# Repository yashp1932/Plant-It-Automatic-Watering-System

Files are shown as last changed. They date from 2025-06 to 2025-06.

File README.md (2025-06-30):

# Plant-It — Smart Watering System 🌿

## ⚙️ Summary 

Plant-It is an **embedded IoT project** built around the ESP8266 microcontroller that **automates indoor plant watering**. It combines AI-powered plant species identification (using Pl@ntNet and OpenAI APIs) with real-time soil moisture sensing to deliver precise watering control. The system integrates with a React-based web dashboard for live monitoring, device management, and personalized care instructions.

**Tech Stack:** ESP8266 · Arduino IDE · Capacitive Soil Moisture Sensor · Relay Module · React.js · Google OAuth · Pl@ntNet API · OpenAI API · REST API  

**Key Features:** Automated AI-driven watering · real-time soil monitoring · image-based plant identification · multi-plant dashboard with user authentication.

---
## 🔍 Explore

🌐 https://plantit.site/login      
📄 [Project Overview (PDF)](project_overview.pdf)      
🎥 [Demo Video](https://www.youtube.com/watch?v=a0oCiGJgBCo)

---

## 🌱 Background

My house is filled with plants thanks to my dad, an avid gardener. With so many plants, it was easy to forget which ones needed watering. Plant-It was created to automate watering, delivering the right amount to each plant precisely when needed.

---

## 🧠 How It Works

Plant-It automatically identifies your plant, retrieves watering needs, and waters based on live soil readings:

1. **Plant Identification**  
   - Snap a photo of the plant and upload to the web app
   - Use **Pl@ntNet API** to detect species  

2. **Optimal Moisture Retrieval**  
   - Feed species data to **OpenAI API**  
   - Retrieve ideal min/max/optimal soil moisture %  

3. **Microcontroller Logic**  
   - ESP8266 connects via **WiFi** to a web app  
   - Receives min/max/optimal VWC thresholds (once per session)  
   - Reads soil moisture from sensor  
   - Controls water pump via relay, watering only as needed  
   - Displays live status on **I2C LCD**
   - Potentiometer enables control over how much water flows out the pipe at a given time

4. **Web Dashboard**  
   - Built with **React**  
   - Uses **Google Accounts** for individual sign-in  
   - Per-user dashboard to view all plants  
   - See each plant’s watering status, species, family, and care tips  
   - ESP8266 can be paired to any plant at any time, allowing easy swap devices between plants

---

## 🔧 Tech Stack

- **ESP8266 (NodeMCU)** microcontroller  
- **Arduino IDE** (firmware development)  
- **React.js** (web app for plant dashboard)  
- **Google OAuth** (user authentication)  
- **Pl@ntNet API** (plant species identification)  
- **OpenAI API** (optimal moisture range generation)  
- **HTTP / REST** (device ↔ web app communication)  
- **Wi-Fi networking** (ESP8266 local server)  

---

## ⚡️ Electronics Used

1. **8-channel relay module**  
2. **5V / 3.3V breadboard power supply**  
3. **Potentiometer** (to tune pump flow rate)  
4. **LCM1602 I2C LCD display**  
5. **Capacitive soil moisture sensor v1.2**  
6. **3–6V submersible water pump**  
7. **ESP8266 (NodeMCU)** microcontroller

---

## 📐 Wiring Diagram

Here’s the full wiring for Plant-It (ESP8266, relay, moisture sensor, LCD, pump):

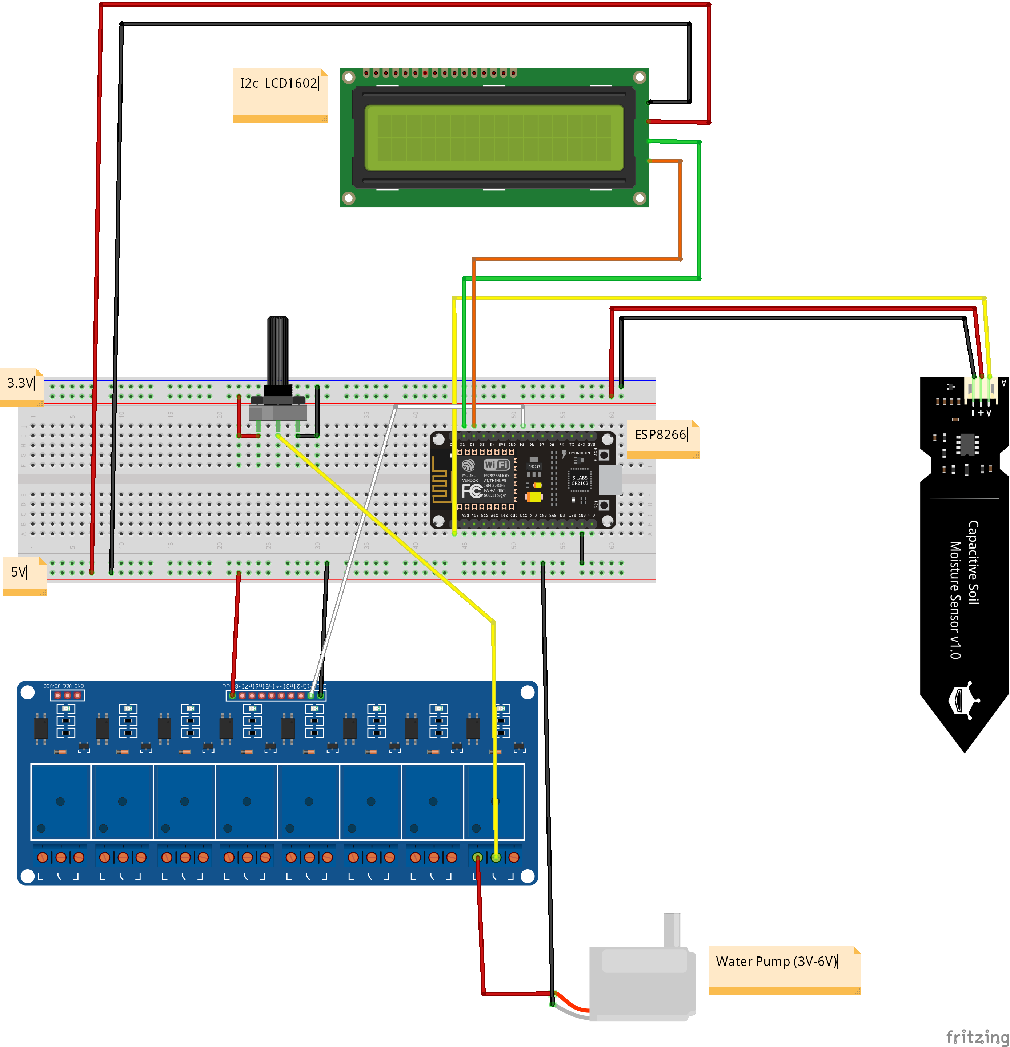
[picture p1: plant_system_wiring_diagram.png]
Plant-It Wiring Diagram


---
## 🚀 Quickstart

```bash
git clone https://github.com/yashp1932/Plant-It-Smart-Watering-System.git
cd Plant-It-Smart-Watering-System
```

**1. In Arduino IDE:**
   - Go to Tools → Board → Boards Manager
   - Install: ESP8266 Boards (by ESP8266 Community)
     
**2. Install required libraries (via Arduino Library Manager):**
   - ESP8266WebServer
   - ArduinoJson
   - LiquidCrystal I2C

**3. Select your board:**
   - Tools → Board → NodeMCU 1.0 (ESP-12E Module)
     
**4. Upload code to ESP8266 (NodeMCU)**      

**5. Power the board — and watch it water!** 🌱

 ---
 
## 🤝 Connect

Have ideas to improve Plant-It? I’d love to hear your feedback, questions, or collaboration ideas!

📧 yash.panchal1932@gmail.com  
🌐 [GitHub](https://github.com/yashp1932)  
💼 [LinkedIn](https://www.linkedin.com/in/yash-panchal-9185aa291/)

📧 Kalpkansara123@gmail.com (project partner)      
🌐 [GitHub](https://github.com/KalpKan/PlantWater)        
💼 [LinkedIn](https://www.linkedin.com/in/kalp-kansara123/)

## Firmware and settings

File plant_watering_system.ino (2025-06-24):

//importing libraries
#include <Wire.h>
#include <LiquidCrystal_I2C.h>
#include <ESP8266WiFi.h>
#include <ESP8266WebServer.h>
#include <ArduinoJson.h>

//storing used pins in variable
#define relayPin    D5    // GPIO14
#define moisturePin A0    // analog input

const int dry         = 452;  // dry calibration
const int wet         = 234;  // wet calibration
const int errorMargin = 3;    // accomodate for sensor errors

// —————— LCD Setup ——————
LiquidCrystal_I2C lcd(0x27, 16, 2);

// —————— Wi-Fi credentials ——————
const char* ssid     = "";
const char* password = "";

// —————— HTTP Server ——————
ESP8266WebServer server(8080); //node on the network it is running on
const char* deviceName = "Plant Watering Device"; //device name to identify on web application

// —————— Plant thresholds ——————
//plant object to hold the properties
struct PlantConfig {
  int minVWC;
  int maxVWC;
  int optimalVWC;
  bool configured;
} plantConfig = {0, 0, 0, false}; //default state

// —————— State ——————
//state variables for watering conditions
bool   isWatering     = false;
bool   thresholdFlag  = false;
String statusMessage  = "";
bool   printedConfig  = false;  // print thresholds once

// — forward declarations —
void connectToWiFi();
void setupWebServer();
int  moisturePercentage(int raw);
void printMoistureAndStatus(int pct, const String &msg);

void setup() {
  Serial.begin(115200); //buad rate for serial communication

  // Relay off initally
  pinMode(relayPin, OUTPUT);
  digitalWrite(relayPin, LOW);

  //Configuring LCD
  lcd.init();
  lcd.backlight();
  lcd.setCursor(0,0); lcd.print("Plant Watering");
  lcd.setCursor(0,1); lcd.print("System Ready!");
  delay(1500);
  lcd.clear();

  connectToWiFi();
  setupWebServer();
  server.begin();

  //Print statements for debugging
  Serial.println("Server listening on port 8080");
  lcd.setCursor(0,0); lcd.print("Waiting for");
  lcd.setCursor(0,1); lcd.print("configuration");
}

void loop() {
  // Always listen for status/configure
  server.handleClient();

  if (!plantConfig.configured) return;

  // Print the thresholds once after config
  if (!printedConfig) {
    Serial.println(">>> Received plant config:");
    Serial.printf("minVWC=%d%%  maxVWC=%d%%  optimalVWC=%d%%\n\n",
                  plantConfig.minVWC,
                  plantConfig.maxVWC,
                  plantConfig.optimalVWC);
    printedConfig = true;
  }

  int raw = analogRead(moisturePin); //read value from sensor
  int pct = moisturePercentage(raw); //convert it to percentage
  Serial.printf("Moisture: %d%%\n", pct); 

  //---------Instructions for when to Water------------
  // Start watering
  if (pct < (plantConfig.minVWC + errorMargin)
      && !isWatering && !thresholdFlag) {
    digitalWrite(relayPin, HIGH);
    isWatering    = true;
    thresholdFlag = false;
    statusMessage = "Watering...     ";
  }
  // Stop watering
  if (isWatering && pct > (plantConfig.optimalVWC + errorMargin)) {
    digitalWrite(relayPin, LOW);
    isWatering    = false;
    thresholdFlag = true;
    statusMessage = "Moisture OK     ";
  }
  // Reset flag
  if (pct > (plantConfig.optimalVWC + 10)) thresholdFlag = false;

  printMoistureAndStatus(pct, statusMessage); //print message on LCD
  delay(2000);
}

void connectToWiFi() {
  //printing on the LCD
  lcd.clear();
  lcd.setCursor(0,0); lcd.print("Connecting WiFi");
  lcd.setCursor(0,1); lcd.print(ssid);

  WiFi.begin(ssid, password); //beginning a connection on the network
  while (WiFi.status() != WL_CONNECTED) { //checking if it is connected
    delay(500);
    Serial.print(".");
  }
  Serial.println("\nWiFi connected");
  //Serial.print("IP = "); Serial.println(WiFi.localIP()); //retrieve the IP address for debugging purposes 

  lcd.clear();
  lcd.setCursor(0,0); lcd.print("WiFi Connected");
  //lcd.setCursor(0,1); lcd.print(WiFi.localIP().toString()); //LCD only accepts string so we have to convert
  delay(2000);
  lcd.clear();
}

void setupWebServer() {
  // Device discovery endpoint
  //checking if plant is configured and has the configured values
  server.on("/status", HTTP_GET, []() {
    server.sendHeader("Access-Control-Allow-Origin", "*");
    server.send(200, "application/json",
                String("{\"device\":\"") + deviceName +
                "\",\"configured\":" + (plantConfig.configured ? "true" : "false") +
                "}");
  });

  // Configure endpoint
  //checking if it recieved the data in JSON format
  server.on("/configure", HTTP_POST, []() {
    if (!server.hasArg("plain")) {
      Serial.println("ERROR: No JSON data received");
      server.send(400, "application/json", "{\"error\":\"No JSON\"}");
      return;
    }
    
    String jsonData = server.arg("plain");
    //debugging purposes to check length of data recieved and what the values are
    Serial.println("=== RECEIVED CONFIGURATION ===");
    Serial.println("Raw JSON: " + jsonData);
    Serial.println("JSON length: " + String(jsonData.length()));
    
    DynamicJsonDocument doc(256);
    auto err = deserializeJson(doc, jsonData);
    if (err) {
      Serial.println("JSON parsing error: " + String(err.c_str()));
      server.send(400, "application/json", "{\"error\":\"Bad JSON\"}");
      return;
    }
    
    Serial.println("JSON parsed successfully");
    
    // Check if fields exist and get their values
    Serial.println("Checking JSON fields:");
    Serial.println("Has minVWC: " + String(doc.containsKey("minVWC") ? "YES" : "NO"));
    Serial.println("Has maxVWC: " + String(doc.containsKey("maxVWC") ? "YES" : "NO"));
    Serial.println("Has optimalVWC: " + String(doc.containsKey("optimalVWC") ? "YES" : "NO"));
    
    // Taking the required values from the JSON and assigning it to our variable
    plantConfig.minVWC = doc["minVWC"];
    plantConfig.maxVWC = doc["maxVWC"];
    plantConfig.optimalVWC = doc["optimalVWC"];
    plantConfig.configured = true;

    //debugging + seeing assigned values
    Serial.println("=== PARSED VALUES ===");
    Serial.println("minVWC: " + String(plantConfig.minVWC));
    Serial.println("maxVWC: " + String(plantConfig.maxVWC));
    Serial.println("optimalVWC: " + String(plantConfig.optimalVWC));
    Serial.println("=====================");
    
    server.send(200, "application/json", "{\"success\":true}");
    Serial.println("→ Configuration received");
  });

  // CORS preflight (requesting the server for access)
  server.on("/configure", HTTP_OPTIONS, []() {
    server.sendHeader("Access-Control-Allow-Origin", "*");
    server.sendHeader("Access-Control-Allow-Methods", "POST,OPTIONS");
    server.sendHeader("Access-Control-Allow-Headers", "Content-Type");
    server.send(200);
  });
}

int moisturePercentage(int raw) {
  int p = (dry - raw) * 100 / (dry - wet);
  return constrain(p, 0, 100);
}

void printMoistureAndStatus(int pct, const String &msg) {
  lcd.clear();
  lcd.setCursor(0,0);
  lcd.print("Moisture: ");
  lcd.print(pct);
  lcd.print("%");
  lcd.setCursor(0,1);
  lcd.print(msg);
} 

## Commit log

2025-06-24 Circuit Model
    [plant_system_model.fzz]
2025-06-24 Wiring Diagram
